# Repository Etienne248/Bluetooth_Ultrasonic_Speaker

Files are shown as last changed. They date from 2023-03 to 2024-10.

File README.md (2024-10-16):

## Bluetooth Phased Array Directional Speaker

This repository contains the source code and hardware schematics for a Bluetooth phased array directional speaker built using ESP32 and ESP-IDF.

The project aims to create a speaker that can project a beam of sound in a specific direction using a phased array, allowing for a more targeted listening experience. The speaker is connected via Bluetooth to any compatible device, such as a smartphone or laptop.

<!-- ![](images/in_box.jpg) 
![](images/component2.jpg)
![](images/main_pcb.jpg)
![](images/pcbs.jpg) -->

<table>
  <tr>
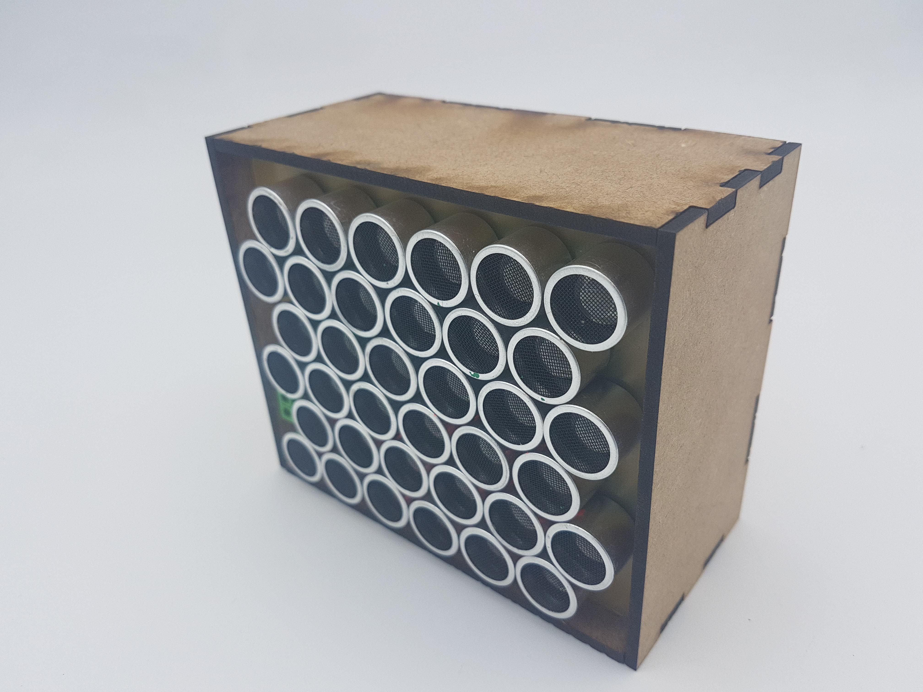
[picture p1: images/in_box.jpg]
    <td></td>
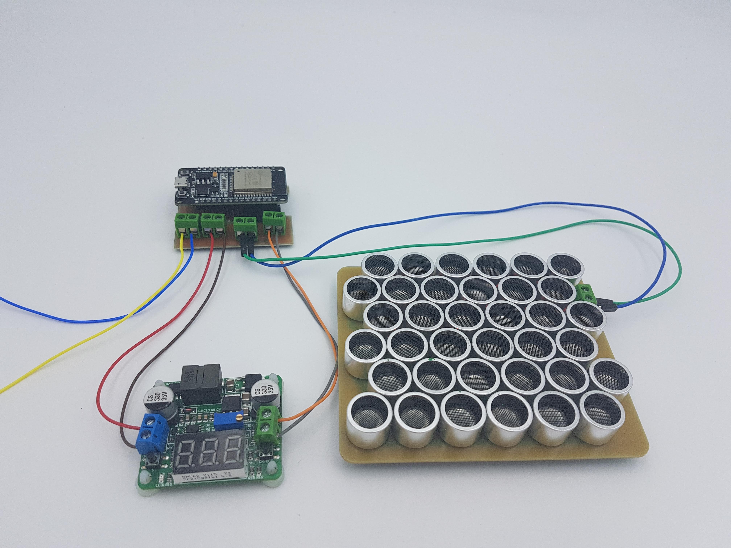
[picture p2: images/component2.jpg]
    <td></td>
  </tr>
  <tr>
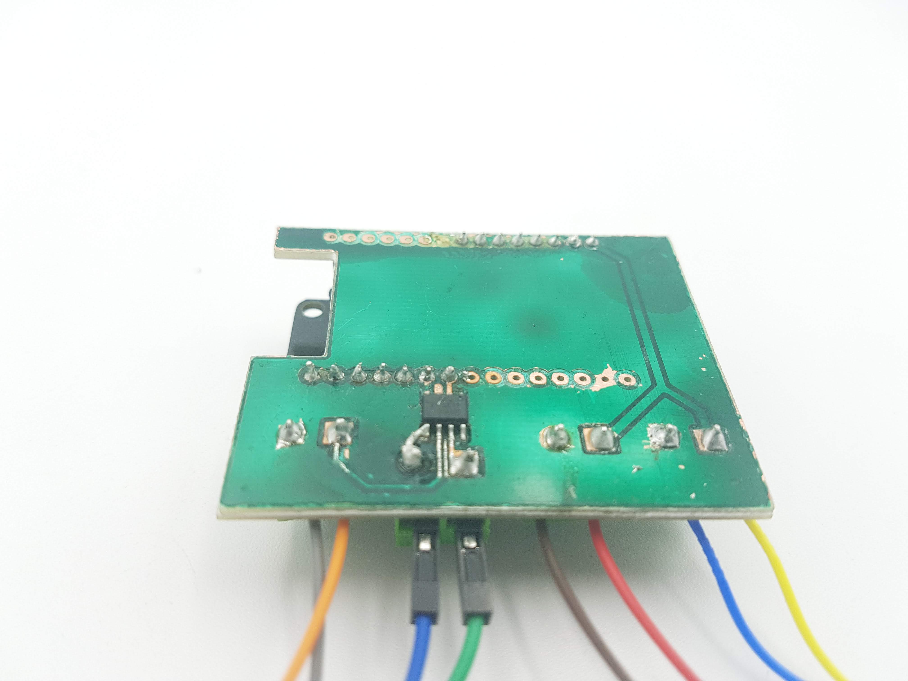
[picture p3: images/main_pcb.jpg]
    <td></td>
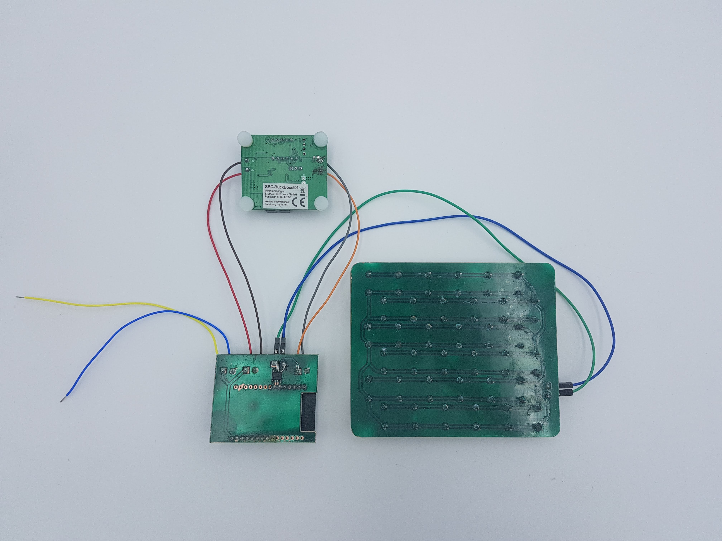
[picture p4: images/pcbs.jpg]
    <td></td>
  </tr>
</table>

## Installation and Usage

To use this project, you will need an ESP32 development board and the ESP-IDF development framework installed on your machine. You can find instructions for installing ESP-IDF with PlatformIO [here](https://docs.platformio.org/en/latest/plus/debugging.html#advanced-configuration).

Once you have ESP-IDF installed with PlatformIO, you can clone this repository and open it in Visual Studio Code with the PlatformIO extension. From there, you can build and flash the firmware to your ESP32 board using the PlatformIO toolbar.

The code for the project can be found in the `Code_Phased_Array_Speaker_esp_idf` directory, and the KiCad files for the hardware can be found in the `Kicad_Phased_Array_Speaker` directory.

After flashing the firmware, you can connect your Bluetooth device to the speaker and begin playing audio. The speaker will project sound in the direction indicated by the phased array.

## Project Structure

The project is organized as follows:

- `Code_Phased_Array_Speaker_esp_idf` directory contains the main application code
- `Kicad_Phased_Array_Speaker` directory contains the hardware schematics and PCB layout files

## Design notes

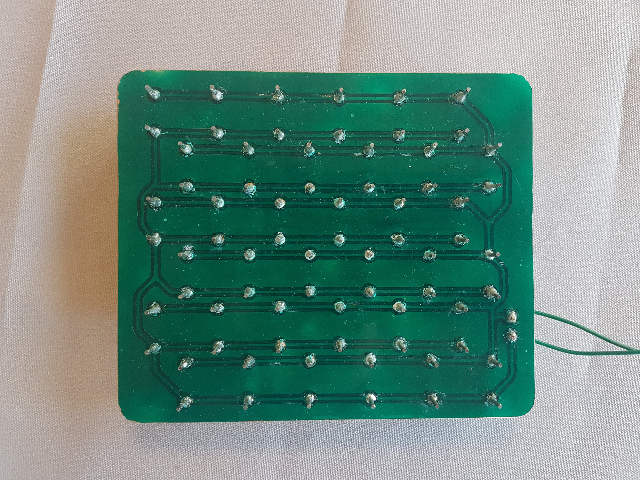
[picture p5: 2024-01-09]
images/array_pcb.jpg

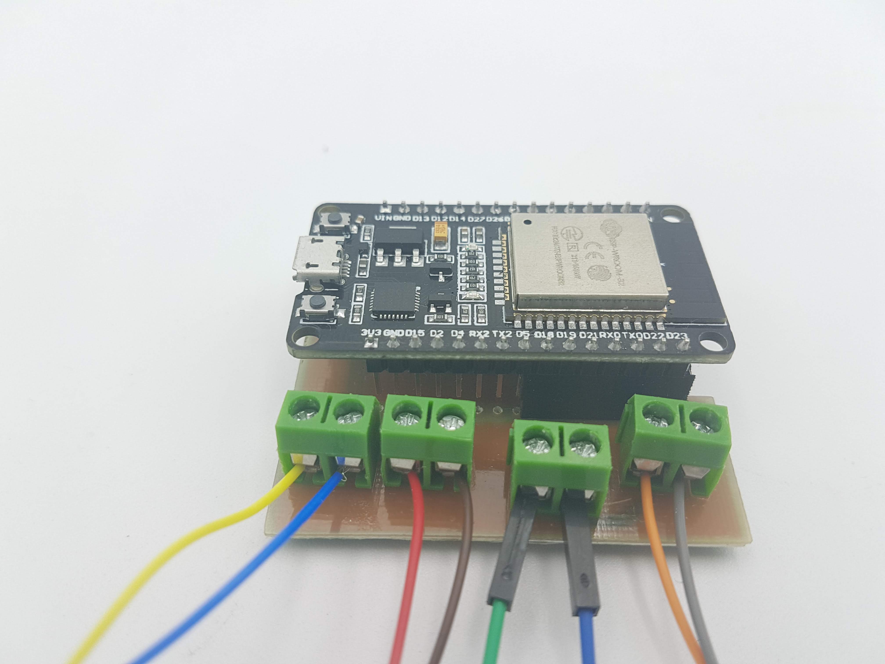
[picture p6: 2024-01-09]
images/esp32.jpg

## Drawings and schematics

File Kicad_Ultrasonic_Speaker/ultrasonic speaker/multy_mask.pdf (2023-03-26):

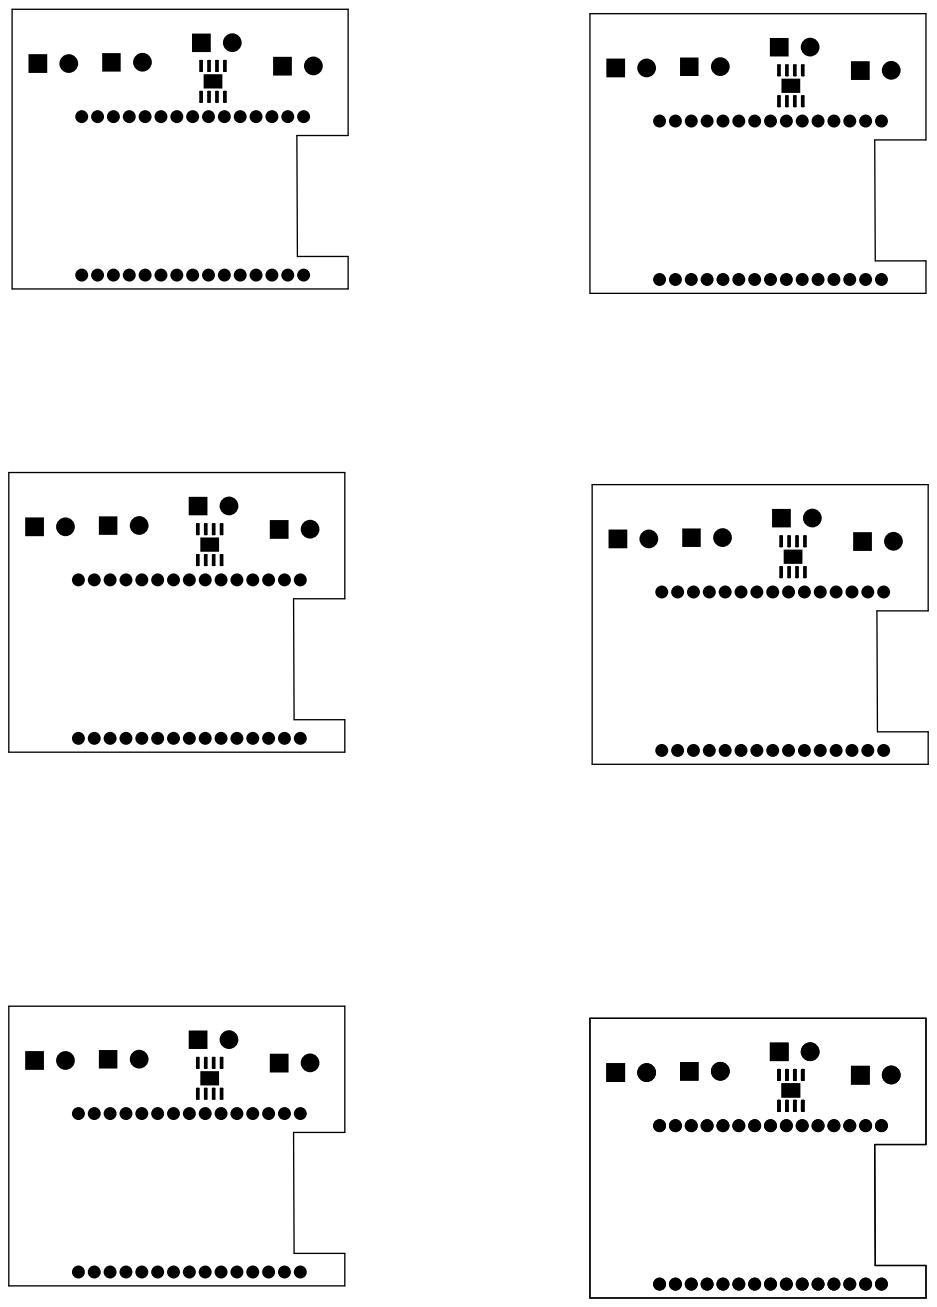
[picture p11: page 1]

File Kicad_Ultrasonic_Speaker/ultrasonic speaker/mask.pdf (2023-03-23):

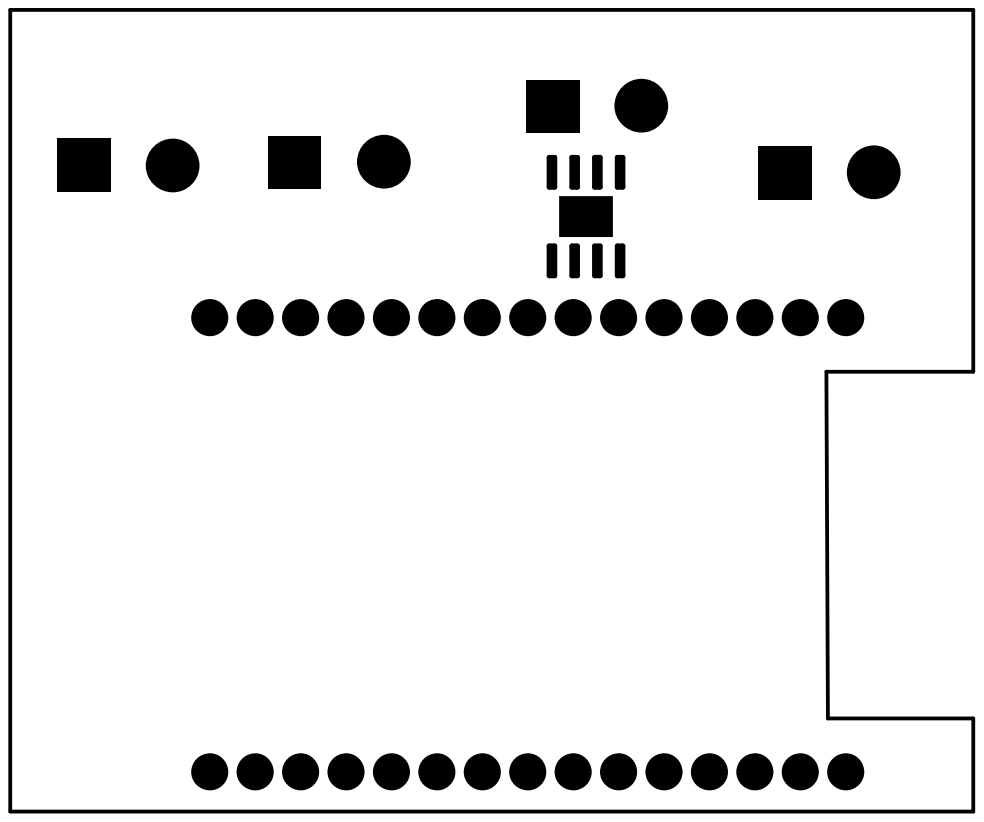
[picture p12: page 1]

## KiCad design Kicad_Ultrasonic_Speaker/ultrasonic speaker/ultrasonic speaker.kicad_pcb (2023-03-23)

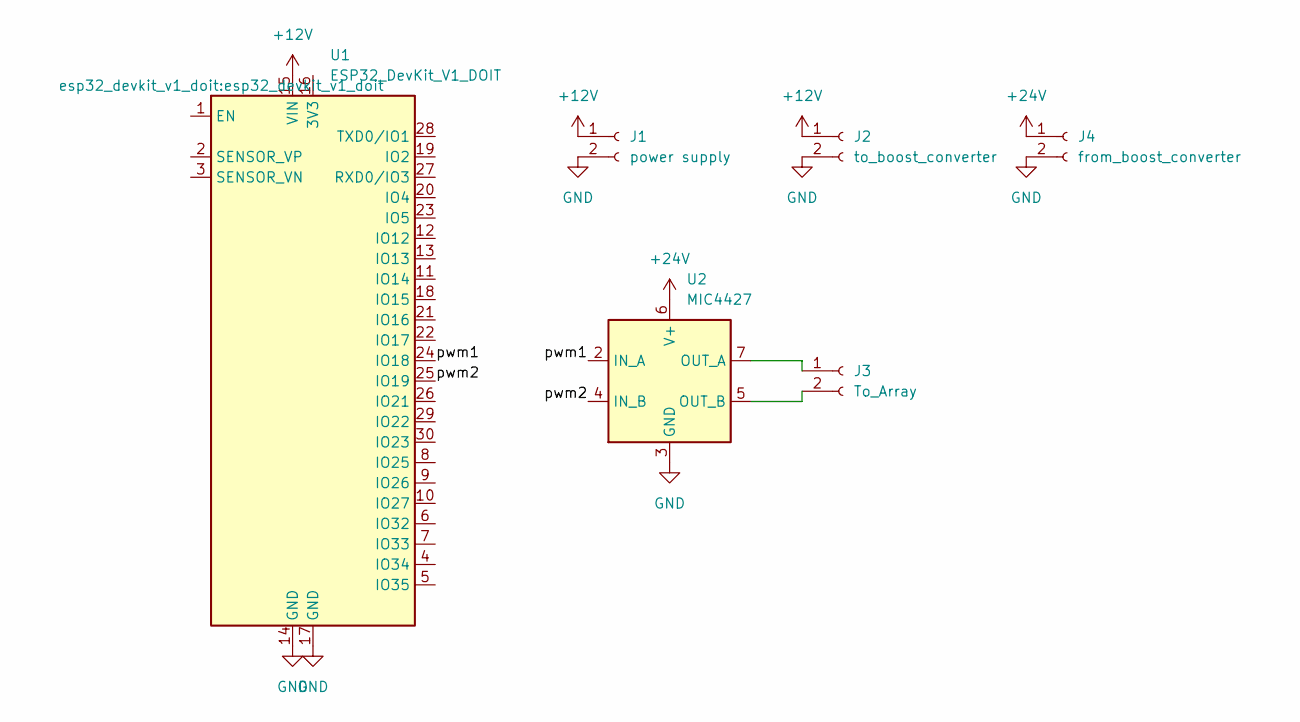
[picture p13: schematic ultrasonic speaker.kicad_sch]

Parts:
J1: power supply; TerminalBlock_Phoenix_MKDS-1,5-2_1x02_P5.00mm_Horizontal
J2: to_boost_converter; TerminalBlock_Phoenix_MKDS-1,5-2_1x02_P5.00mm_Horizontal
J3: To_Array; TerminalBlock_Phoenix_MKDS-1,5-2_1x02_P5.00mm_Horizontal
J4: from_boost_converter; TerminalBlock_Phoenix_MKDS-1,5-2_1x02_P5.00mm_Horizontal
U1: ESP32_DevKit_V1_DOIT; esp32_devkit_v1_doit
U2: MIC4427; Fet_driver_SOIC-8-1EP_3.9x4.9mm_P1.27mm_EP2.29x3mm

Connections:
+12V: J1.1, J2.1, U1.15 (VIN)
+24V: J4.1, U2.6 (V+)
/pwm1: U1.24 (IO18), U2.2 (IN_A)
/pwm2: U1.25 (IO19), U2.4 (IN_B)
GND: J1.2, J2.2, J4.2, U1.14 (GND), U1.17 (GND), U2.3 (GND)
unnamed: J3.1, U2.7 (OUT_A)
unnamed: J3.2, U2.5 (OUT_B)

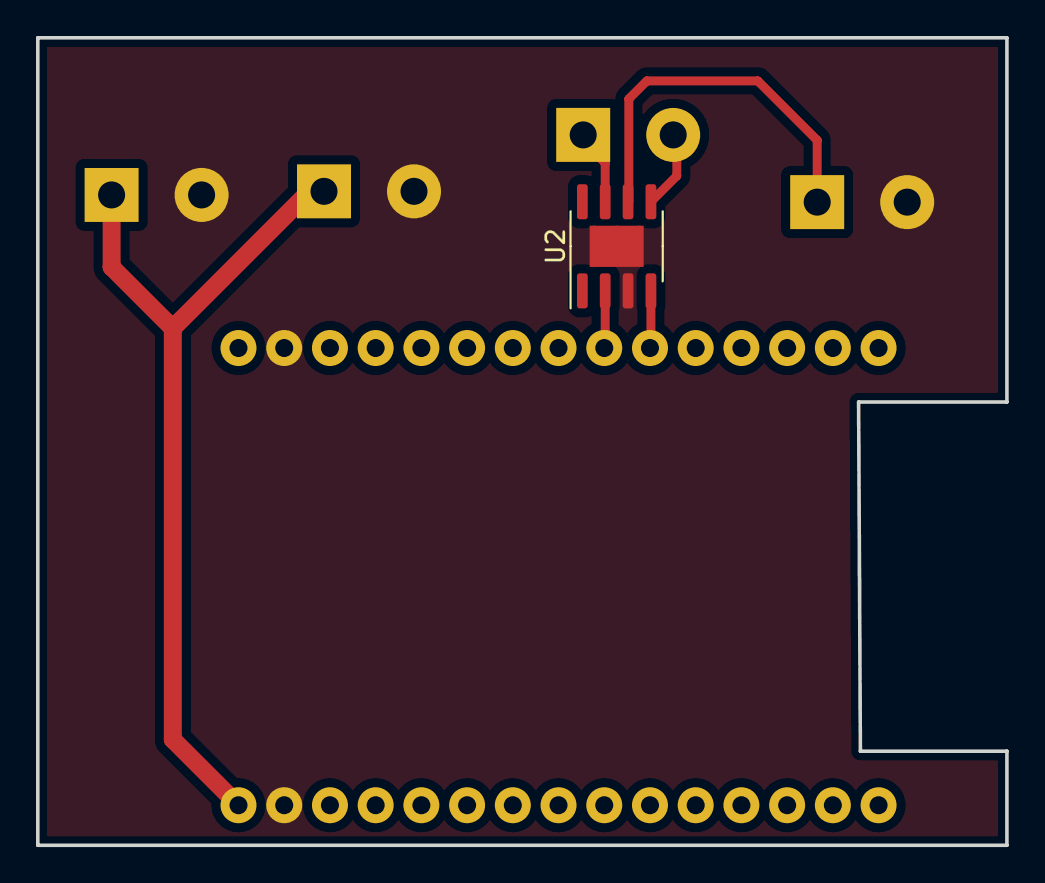
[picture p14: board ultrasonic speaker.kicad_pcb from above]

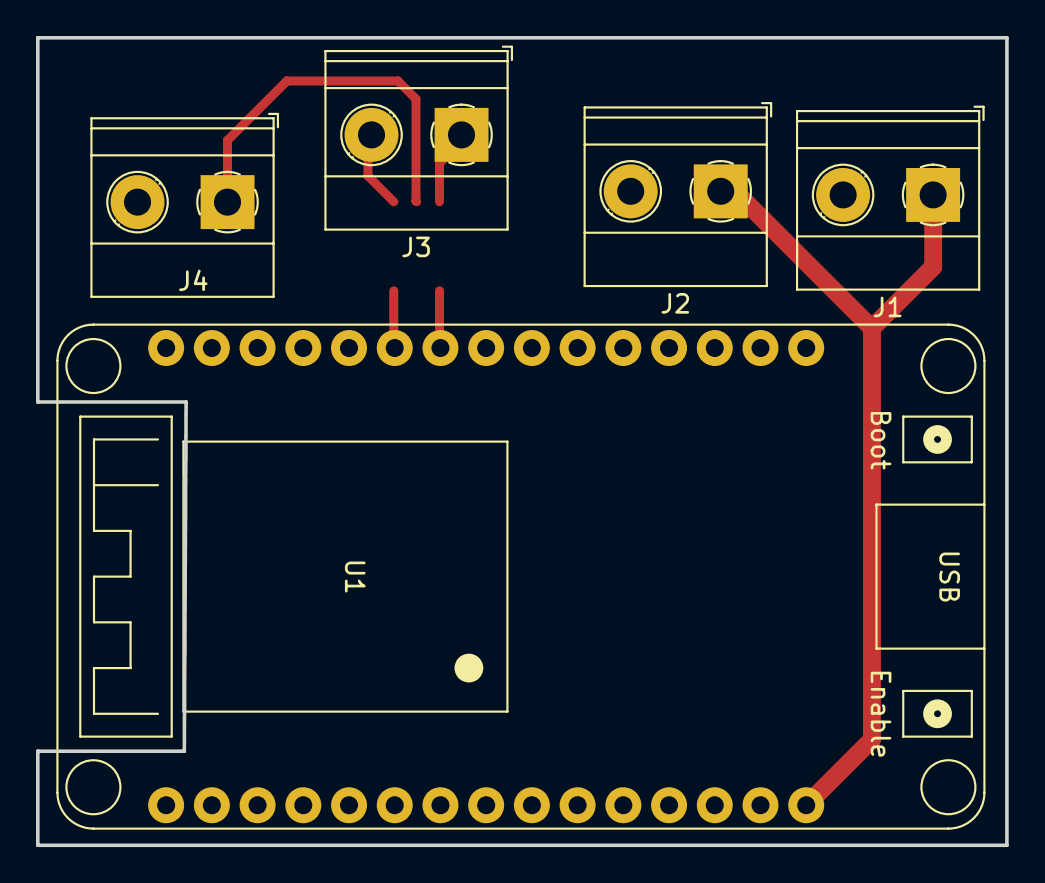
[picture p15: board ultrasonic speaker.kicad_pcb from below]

Board: 2 copper layers, 53.8 x 44.9 mm, 6 parts (5 on the bottom side), 7 nets.

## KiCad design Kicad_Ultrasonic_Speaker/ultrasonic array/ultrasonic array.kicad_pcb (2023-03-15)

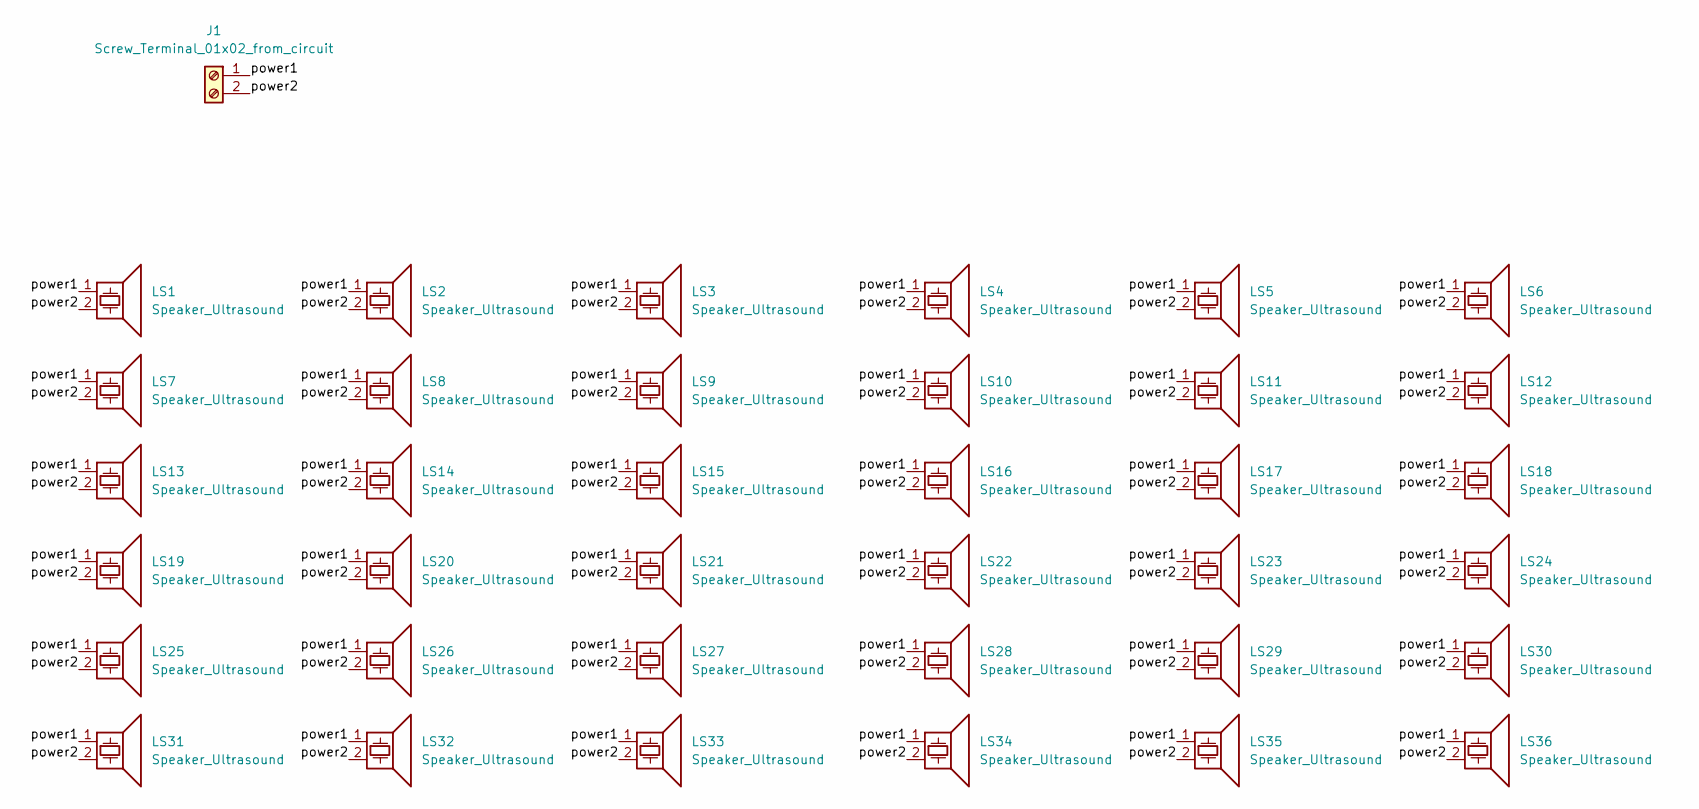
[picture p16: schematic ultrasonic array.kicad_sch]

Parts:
J1: Screw_Terminal_01x02_from_circuit; TerminalBlock_Phoenix_MKDS-1,5-2_1x02_P5.00mm_Horizontal
LS1, LS2, LS3, LS4, LS5, LS6, LS7, LS8, LS9, LS10, LS11, LS12, LS13, LS14, LS15, LS16, LS17, LS18, LS19, LS20, LS21, LS22, LS23, LS24, LS25, LS26, LS27, LS28, LS29, LS30, LS31, LS32, LS33, LS34, LS35, LS36: Speaker_Ultrasound; ultrasonic_D16mm_P10mm

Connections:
/power1: J1.1, LS1.1, LS2.1, LS3.1, LS4.1, LS5.1, LS6.1, LS7.1, LS8.1, LS9.1, LS10.1, LS11.1, LS12.1, LS13.1, LS14.1, LS15.1, LS16.1, LS17.1, LS18.1, LS19.1, LS20.1, LS21.1, LS22.1, LS23.1, LS24.1, LS25.1, LS26.1, LS27.1, LS28.1, LS29.1, LS30.1, LS31.1, LS32.1, LS33.1, LS34.1, LS35.1, LS36.1
/power2: J1.2, LS1.2, LS2.2, LS3.2, LS4.2, LS5.2, LS6.2, LS7.2, LS8.2, LS9.2, LS10.2, LS11.2, LS12.2, LS13.2, LS14.2, LS15.2, LS16.2, LS17.2, LS18.2, LS19.2, LS20.2, LS21.2, LS22.2, LS23.2, LS24.2, LS25.2, LS26.2, LS27.2, LS28.2, LS29.2, LS30.2, LS31.2, LS32.2, LS33.2, LS34.2, LS35.2, LS36.2

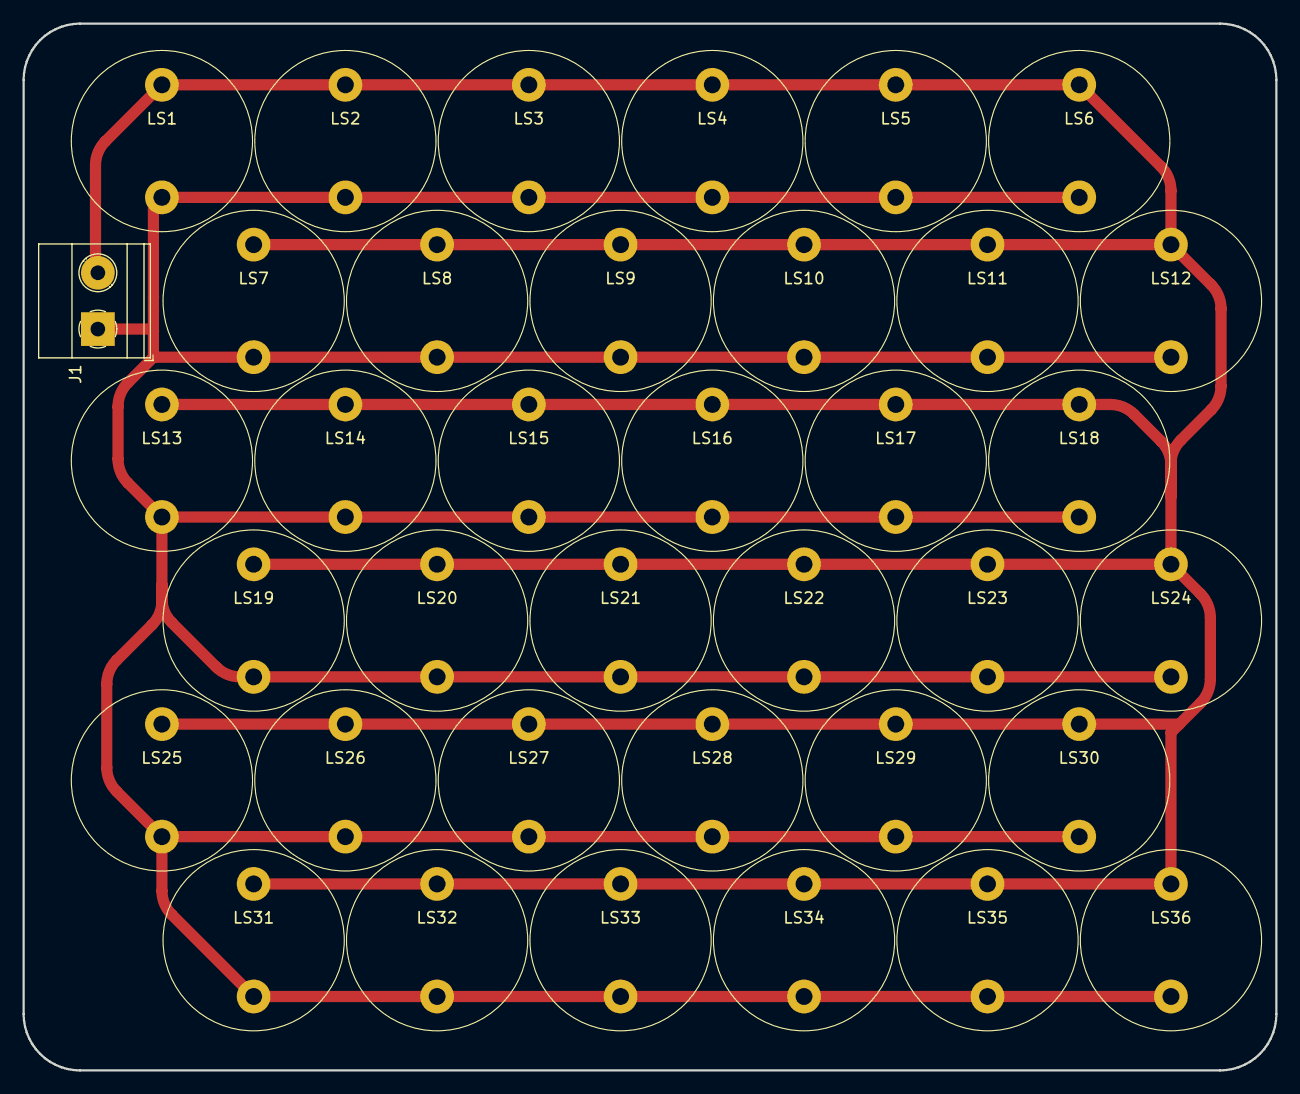
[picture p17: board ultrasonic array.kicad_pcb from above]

Board: 2 copper layers, 111.3 x 93.0 mm, 37 parts (0 on the bottom side), 2 nets.

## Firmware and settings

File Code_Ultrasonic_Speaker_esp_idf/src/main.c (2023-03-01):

#include "mcpwm_gen.h"
#include "bt_main.h"
#include "glob_var.h"


void app_main(void)
{
    mcpwm_init();
    bt_app_main();
    while (1)
    {
        ESP_LOGI(TAG, "Angle of rotation: %d", angle);
        // Add delay, since it takes time for servo to rotate, usually 200ms/60degree rotation under 5V power supply
        // vTaskDelay(pdMS_TO_TICKS(1));
        //ESP_LOGI(TAG, "X=: %d", x);
        printf("x = %d\n",x);
        x=0;
        //printf(esp_clk_cpu_freq());
        vTaskDelay(100);
    }
}

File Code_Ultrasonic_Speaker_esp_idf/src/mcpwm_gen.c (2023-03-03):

/*
 * SPDX-FileCopyrightText: 2022 Espressif Systems (Shanghai) CO LTD
 *
 * SPDX-License-Identifier: Apache-2.0
 */

#include "mcpwm_gen.h"
#include "glob_var.h"

RingbufHandle_t ringbuf_pwm = NULL;

volatile int x = 0;
volatile int angle = 1010*DIVISION;
volatile int step = 1;

UBaseType_t uxItemsWaiting;

static uint8_t count_for_data_skip = 0;


inline uint32_t example_angle_to_compare(int angle)
{
    if (angle>=SERVO_MAX_DEGREE)angle = SERVO_MAX_DEGREE-1;
    else if (angle<=SERVO_MIN_DEGREE)angle = SERVO_MIN_DEGREE+1;
    int v = (angle - SERVO_MIN_DEGREE) * (SERVO_MAX_PULSEWIDTH_US - SERVO_MIN_PULSEWIDTH_US) / (SERVO_MAX_DEGREE - SERVO_MIN_DEGREE) + SERVO_MIN_PULSEWIDTH_US;
    return v;
}

bool change_duty_on_empty(mcpwm_timer_handle_t timer, const mcpwm_timer_event_data_t *edata, void *comparator)
{
    x++;
    /*
    ESP_ERROR_CHECK(mcpwm_comparator_set_compare_value(comparator, example_angle_to_compare(angle)));
    if ((angle + step) > 2000*DIVISION || (angle + step) < 1000*DIVISION)
    {
        step *= -1;
    }
    angle += step;*/

    //vRingbufferGetInfo(ringbuf_pwm, NULL, NULL, NULL, NULL, uxItemsWaiting);
    size_t item_size;
    static int16_t * item = NULL;
    item = xRingbufferReceiveUpToFromISR(ringbuf_pwm, &item_size, sizeof(uint32_t));
    if (item != NULL ){
        angle = item[0]+item[1];
        vRingbufferReturnItem(ringbuf_pwm, (void *)item);
        //ESP_LOGI(TAG, "bluetooth Angle of rotation: %d", angle);
    }
    else angle = 0;
    if (uxItemsWaiting > 1024*4 && count_for_data_skip >9){
        item = xRingbufferReceiveUpToFromISR(ringbuf_pwm, &item_size, sizeof(uint32_t));
        if (item != NULL ){
            angle = angle+(item[0]+item[1])/2;
            count_for_data_skip=0;
            vRingbufferReturnItem(ringbuf_pwm, (void *)item);
        }
    }
    ESP_ERROR_CHECK(mcpwm_comparator_set_compare_value(comparator, example_angle_to_compare(angle)));

    count_for_data_skip++;


    return true;
}

void mcpwm_init(){
    esp_pm_configure(ESP_PM_CPU_FREQ_MAX);

    ESP_LOGI(TAG, "Create timer and operator");
    mcpwm_timer_handle_t timer = NULL;
    mcpwm_timer_config_t timer_config = {
        .group_id = 0,
        .clk_src = MCPWM_TIMER_CLK_SRC_DEFAULT,
        .resolution_hz = SERVO_TIMEBASE_RESOLUTION_HZ,
        .period_ticks = SERVO_TIMEBASE_PERIOD,
        .count_mode = MCPWM_TIMER_COUNT_MODE_UP,
    };
    ESP_ERROR_CHECK(mcpwm_new_timer(&timer_config, &timer));

    mcpwm_oper_handle_t oper = NULL;
    mcpwm_operator_config_t operator_config = {
        .group_id = 0, // operator must be in the same group to the timer
    };
    ESP_ERROR_CHECK(mcpwm_new_operator(&operator_config, &oper));

    ESP_LOGI(TAG, "Connect timer and operator");
    ESP_ERROR_CHECK(mcpwm_operator_connect_timer(oper, timer));

    ESP_LOGI(TAG, "Create comparator and generator from the operator");
    mcpwm_cmpr_handle_t comparator = NULL;
    mcpwm_comparator_config_t comparator_config = {
        .flags.update_cmp_on_tez = true,
    };
    ESP_ERROR_CHECK(mcpwm_new_comparator(oper, &comparator_config, &comparator));

    mcpwm_gen_handle_t generator = NULL;
    mcpwm_generator_config_t generator_config = {
        .gen_gpio_num = 18,
        .flags.invert_pwm = true,
    };
    ESP_ERROR_CHECK(mcpwm_new_generator(oper, &generator_config, &generator));

    mcpwm_gen_handle_t generatorB = NULL;
    mcpwm_generator_config_t generatorB_config = {
        .gen_gpio_num = 19,
        .flags.invert_pwm = true,
    };
    ESP_ERROR_CHECK(mcpwm_new_generator(oper, &generatorB_config, &generatorB));

    // set the initial compare value, so that the servo will spin to the center position
    ESP_ERROR_CHECK(mcpwm_comparator_set_compare_value(comparator, example_angle_to_compare(0)));

    ESP_LOGI(TAG, "Set generator action on timer and compare event");
    // go high on counter empty
    ESP_ERROR_CHECK(mcpwm_generator_set_actions_on_timer_event(generator,
                                                               MCPWM_GEN_TIMER_EVENT_ACTION(MCPWM_TIMER_DIRECTION_UP, MCPWM_TIMER_EVENT_EMPTY, MCPWM_GEN_ACTION_HIGH),
                                                               MCPWM_GEN_TIMER_EVENT_ACTION_END()));
    // go low on compare threshold
    ESP_ERROR_CHECK(mcpwm_generator_set_actions_on_compare_event(generator,
                                                                 MCPWM_GEN_COMPARE_EVENT_ACTION(MCPWM_TIMER_DIRECTION_UP, comparator, MCPWM_GEN_ACTION_LOW),
                                                                 MCPWM_GEN_COMPARE_EVENT_ACTION_END()));

    mcpwm_dead_time_config_t dead_time_config = {
        .posedge_delay_ticks = 1000,
        .negedge_delay_ticks = 1000,
        //.flags.invert_output = true,
    };
    ESP_ERROR_CHECK(mcpwm_generator_set_dead_time(generator, generatorB, &dead_time_config));

    ESP_LOGI(TAG, "register event callbacks\r\n");
    mcpwm_timer_event_callbacks_t cbs = {
        .on_empty = change_duty_on_empty,
    };
    ESP_ERROR_CHECK(mcpwm_timer_register_event_callbacks(timer, &cbs, comparator));

    ESP_LOGI(TAG, "ring buffer creation\r\n");
    if ((ringbuf_pwm = xRingbufferCreate(8 * 1024, RINGBUF_TYPE_BYTEBUF)) == NULL) {
        return;
    }
    vRingbufferGetInfo(ringbuf_pwm, NULL, NULL, NULL, NULL, &uxItemsWaiting);

    ESP_LOGI(TAG, "Enable and start timer");
    ESP_ERROR_CHECK(mcpwm_timer_enable(timer));
    ESP_ERROR_CHECK(mcpwm_timer_start_stop(timer, MCPWM_TIMER_START_NO_STOP));
    
};

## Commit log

2023-02-28 source and header for pwm
2023-03-01 add pwm ringbuffer
2023-03-10 kicad 6.0
    [ultrasonic array.kicad_pcb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]
2023-03-15 hole enlargement
    [ultrasonic array.kicad_pcb]
2023-03-22 change for boost converter
    [ultrasonic speaker-B_Cu.gbr, ultrasonic speaker-B_Mask.gbr, ultrasonic speaker-B_Paste.gbr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]
2023-03-22 simple save
    [ultrasonic speaker.kicad_sch]
2023-03-23 modification of esp32 pcb
    [ultrasonic speaker.kicad_pcb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]
2024-01-09 add images
    [freerouting.dsn, ultrasonic_array.kicad_sch]
